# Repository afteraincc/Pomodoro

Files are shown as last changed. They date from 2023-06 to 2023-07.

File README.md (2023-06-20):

>
> 视频介绍：[不会闹铃的番茄时钟](https://www.bilibili.com/video/BV1qc411M7Mi/)
>

### 简介

想法来自“番茄（Pomodoro）工作法”，一种简单易行的时间管理方法。将时间划分为小块，包含专注的工作时间和发散的休息时间。劳逸结合的方式有利于获得较高的工作效率

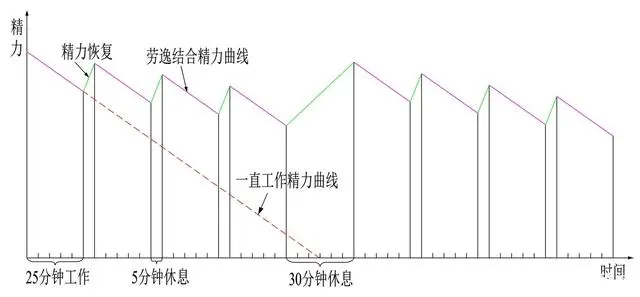
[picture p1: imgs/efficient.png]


### 特色功能

- 简单易用：翻转触发操作

- 劳逸结合：工作状态自动进入休息状态 + 不能关闭的窗口

- 减少干扰：自动开/关即时通讯软件（现支持微信/钉钉）

- 超长续航：长达10小时续航的锂电池，能满足一天的使用

- 插件机制：可以自己实现专用的状态显示效果，例如使用各种开发板附带的例子：点亮LED灯

### 客户端（client目录）

为了能跨平台使用，技术上选择了[Electron](https://www.electronjs.org)

- 编译/构建

	- 先安装[Node.js](https://nodejs.org/en/download)
	
	- 安装依赖

		`npm install`
	
	- 构建

		`npm run build`

- 调试

	由于UI的本质是一个Chrome浏览器，所以可以用Chrome的快捷键`Ctrl + Shift + I`/`Cmd + Opt + I`打开开发者工具
	
- 插件机制

	目录`src/notify-plugins`下新建一个js，模版如下，在感兴趣的状态事件中写相应代码即可
	
	```
	class NotifyPluginXXX {
    onWork() {
    }
    onBreak() {
    }
    onWorkEnd(force) {
    }
    onBreakEnd(force) {
    }
}
export default NotifyPluginXXX
	```

### 固件（fireware目录）

- 显示驱动：TFT_eSPI库

	Visual Studio Code + platformio的配置方法

	```
	配置文件`platformio.ini`增加`build_flags = -I include/tft`，然后`tft_setup.h`放在`include/tft`目录下
	```

- UI：LVGL库

	Visual Studio Code + platformio的配置方法

	```
	配置文件`platformio.ini`增加`build_flags = -I include/lvgl`，然后`lv_conf.h`放在`include/lvgl`目录下
	```

- 陀螺仪MPU6050：I2Cdevlib-MPU6050库

### 硬件（hardware目录）

芯片：USB TypeC接口，ESP32-C3蓝牙，MPU6050陀螺仪，CH340C串口，AMS-1117 3.3V电压转换，IP5306充放电

内容包括原理+PCB和BOM

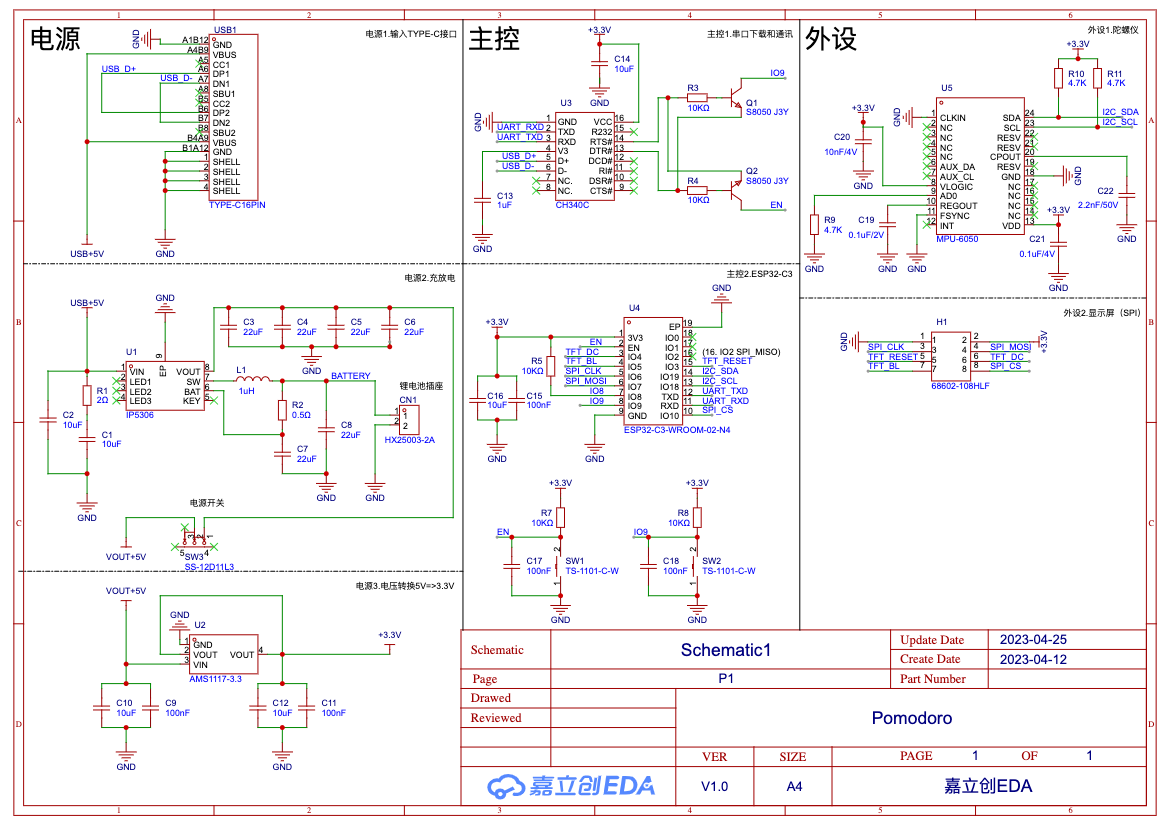
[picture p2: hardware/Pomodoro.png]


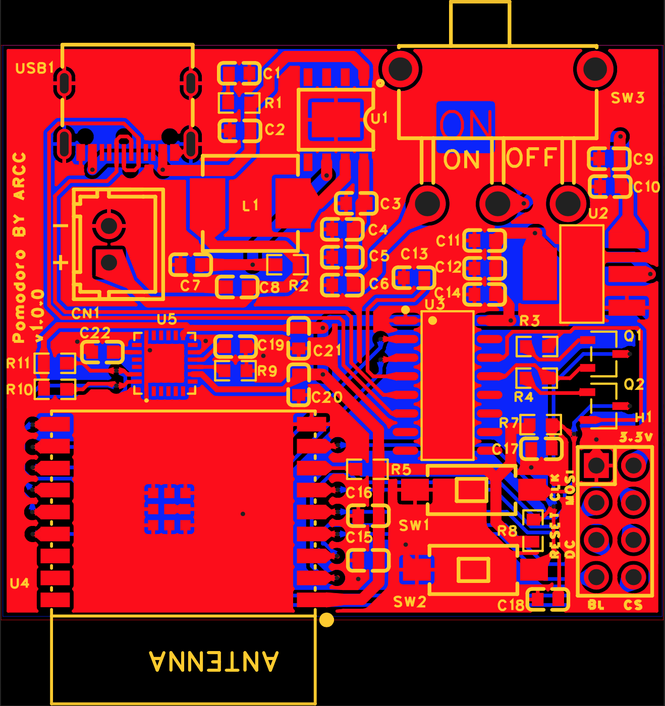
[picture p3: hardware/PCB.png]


### 外壳（3d-model目录）

注意外壳的尺寸是按显示屏和电池定制的，如果选择不同的电池（40x40x10mm）和显示屏（28x40mm）需要注意相应修改

### 注意事项

- ESP32-C3的内存不足

	由于显示屏/蓝牙/陀螺仪用去不少内存，LVGL界面的建议字体最大32，更大的字体容易引起crash（不断循环重启）

- 焊接PCB

	- 焊接IP5306时，底部GND需要焊接到焊盘，否则电压/电流不稳定引起一些奇怪的问题，例如电脑无法识别CH340芯片的串口。建议用风枪+锡膏

	- MPU6050是QFN封装，需要用风枪焊接

- 使用嘉立创EDA（专业版）

	用嘉立创的注意一下，设计时，库里提供的MPU6050是24根引脚，PCB布线时，有一个底部GND无法连接，删除后正常。实际使用下来，发现并不影响功能，主要应该是因为MPU6050本身有一个引脚已经连接到底部GND地线

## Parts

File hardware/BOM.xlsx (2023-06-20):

No. | Quantity | Comment | Designator | Footprint | Value | Manufacturer Part | Manufacturer | Supplier Part | Supplier
1 | 6 | 10uF | C1,C2,C10,C12,C14,C16 | C0603 | 10uF
2 | 6 | 22uF | C3,C4,C5,C6,C7,C8 | C0603 | 22uF
3 | 5 | 100nF | C9,C11,C15,C17,C18 | C0603 | 100nF
4 | 1 | 1uF | C13 | C0603 | 1uF
5 | 1 | 0.1uF/2V | C19 | C0603 | 0.1uF/2V
6 | 1 | 10nF/4V | C20 | C0603 | 10nF/4V
7 | 1 | 0.1uF/4V | C21 | C0603 | 0.1uF/4V
8 | 1 | 2.2nF/50V | C22 | C0603 | 2.2nF/50V
9 | 1 | HX25003-2A | CN1 | CONN-TH_2P-P2.50_HX25003-2A |  | HX25003-2A | HX(红星) | C442299 | LCSC
10 | 1 | 68602-108HLF | H1 | HDR-TH_8P-P2.54-V-M-R2-C4-S2.54 |  | 68602-108HLF | Amphenol | C168672 | LCSC
11 | 1 | 1uH | L1 | IND-SMD_L6.5-W6.5_IHLP-2525 | 1uH | IHLP2525CZER1R0M01 | VISHAY(威世) | C845018 | LCSC
12 | 2 | S8050 J3Y | Q1,Q2 | SOT-23-3_L3.0-W1.7-P0.95-LS2.9-BR |  | S8050 J3Y | CJ（江苏长电/长晶） | C2146 | LCSC
13 | 1 | 2Ω | R1 | R0603 | 2Ω
14 | 1 | 0.5Ω | R2 | R0603 | 0.5Ω
15 | 5 | 10KΩ | R3,R4,R5,R7,R8 | R0603 | 10KΩ
16 | 3 | 4.7K | R9,R10,R11 | R0603 | 4.7K
17 | 2 | TS-1101-C-W | SW1,SW2 | SW-SMD_L6.0-W3.3-LS8.0 |  | TS-1101-C-W | XKB Connectivity(中国星坤) | C318938 | LCSC
18 | 1 | SS-12D11L3 | SW3 | SW-TH_SS-12D11L3 |  | SS-12D11L3 | XKB Connectivity(中国星坤) | C843366 | LCSC
19 | 1 | IP5306 | U1 | ESOP-8_L4.9-W3.9-P1.27-LS6.0-BL-EP |  | IP5306 | INJOINIC(英集芯) | C181692 | LCSC
20 | 1 | AMS1117-3.3 | U2 | SOT-223-3_L6.5-W3.4-P2.30-LS7.0-BR |  | AMS1117-3.3 | AMS | C6186 | LCSC
21 | 1 | CH340C | U3 | SOP-16_L10.0-W3.9-P1.27-LS6.0-BL |  | CH340C | WCH(南京沁恒) | C84681 | LCSC
22 | 1 | ESP32-C3-WROOM-02-N4 | U4 | BULETM-SMD_ESPRESSIF_ESP32-C3-WROOM-02-N4-4MB |  | ESP32-C3-WROOM-02-N4 | ESPRESSIF(乐鑫) | C2934560 | LCSC
23 | 1 | MPU-6050 | U5 | QFN-24_L4.0-W4.0-P0.50-BL-MPU-6050 |  | MPU-6050 | TDK InvenSense(应美盛) | C24112 | LCSC
24 | 1 | TYPE-C16PIN | USB1 | USB-C-SMD_TYPE-C16PIN |  | TYPE-C16PIN | SHOU HAN(首韩) | C393939 | LCSC

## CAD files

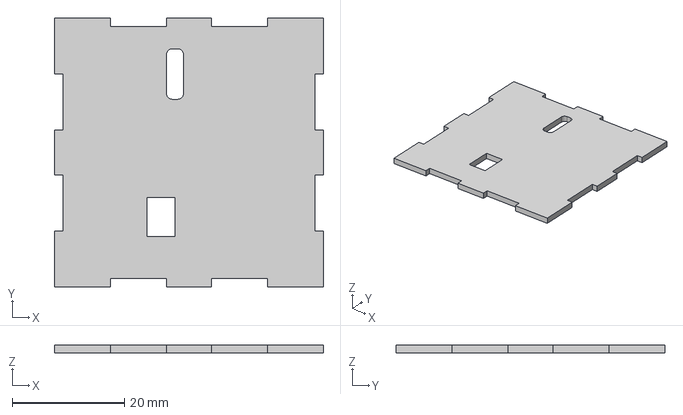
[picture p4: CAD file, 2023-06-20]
3d-model/lid.step
48.0 x 48.0 x 1.50 mm

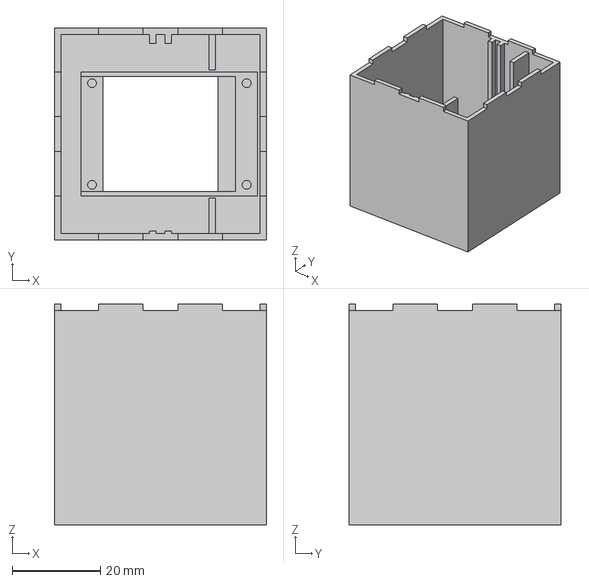
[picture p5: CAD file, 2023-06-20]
3d-model/box.step
48.0 x 48.0 x 50.0 mm

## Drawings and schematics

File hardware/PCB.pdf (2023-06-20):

# ONONOFF

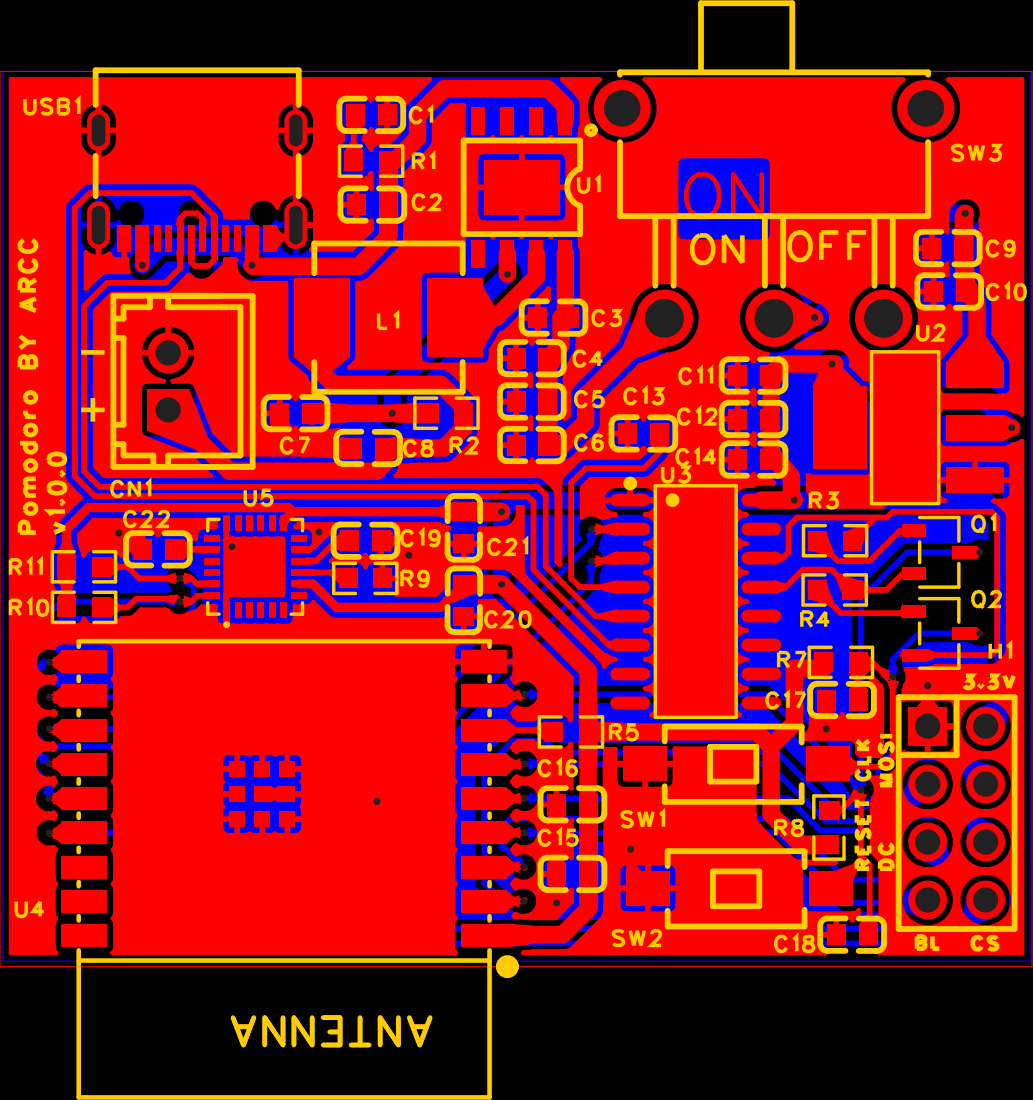
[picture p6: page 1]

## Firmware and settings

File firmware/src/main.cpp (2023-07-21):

#include <Arduino.h>
#include <Esp.h>
#include <Ticker.h>
#include "ble.h"
#include "cfg.h"
#include "screen.h"
#include "mainpage.h"
#include "loopticker.h"
#include "cube.h"

static Screen screen;
static MainPage mainPage;

static PomodoroBLE *pomodoroBLE = NULL;
static PomodoroStatus pomodoroStatus = PomodoroStatus::Idle;
static bool isAutoBreak = false;

static Ticker timer;
static uint32_t secondNum = 0;
static uint32_t timeoutRetryCount = 3; // 超时通知重试次数(秒数)，确保客户端接收到结束消息

// longIntervalSecond: 未连接时，BLE定时广播
static LoopTicker loopTicker(5, 10, 1);

static Cube cube;
static int preFaceId = 0;

void echoSystemInfo()
{
  Serial.printf("chip revision: %d\n", ESP.getChipRevision());
  Serial.printf("chip model: %s\n", ESP.getChipModel());
  Serial.printf("chip cores: %d\n", ESP.getChipCores());
  Serial.printf("cpu FreqMHz: %d\n", ESP.getCpuFreqMHz());
  Serial.printf("sdk version: %s\n", ESP.getSdkVersion());

  Serial.printf("heap size: %d\n", ESP.getHeapSize());
  Serial.printf("free heap: %d\n", ESP.getFreeHeap());
  Serial.printf("mini free heap: %d\n", ESP.getMinFreeHeap());
  Serial.printf("max alloc heap: %d\n", ESP.getMaxAllocHeap());

  Serial.printf("psram size: %d\n", ESP.getPsramSize());
  Serial.printf("free psram: %d\n", ESP.getFreePsram());
  Serial.printf("mini free psram: %d\n", ESP.getMinFreePsram());
  Serial.printf("max alloc psram: %d\n", ESP.getMaxAllocPsram());

  Serial.printf("flash size: %d\n", ESP.getFlashChipSize());
  Serial.printf("flash speed: %d\n", ESP.getFlashChipSpeed());
  Serial.printf("flash mode: %d\n", ESP.getFlashChipMode());
}

void initScreen()
{
  screen.init(240, 240);
  mainPage.init();
  lv_timer_handler();
}

void initBLE()
{
  PomodoroCfg.loadCfg();

  pomodoroBLE = new PomodoroBLE();
  pomodoroBLE->setWorkMinute(PomodoroCfg.getWorkMinute());
  pomodoroBLE->init();
  Serial.printf("PomodoroBLE work minute: %d\n", pomodoroBLE->getWorkMinute());

  mainPage.updateWorkProgress(pomodoroBLE->getWorkMinute() * 60, 0);
}

void setup()
{
  Serial.begin(115200);
  echoSystemInfo();

  initScreen();
  initBLE();

  cube.init();
}

bool workTriggerOn()
{
  return !digitalRead(0x9);
}

bool cancelTimer()
{
  if (!timer.active())
    return false;

  timer.detach();
  return true;
}

void breakTriggerHandle();
void IRAM_ATTR onWorkTimer()
{
  bool timeout = false;
  bool timeoutRetrying = false;

  secondNum++;
  if (secondNum > pomodoroBLE->getWorkMinute() * 60)
    timeoutRetrying = true;
  if (secondNum > pomodoroBLE->getWorkMinute() * 60 + timeoutRetryCount)
    timeout = true;

  if (timeout)
  {
    isAutoBreak = true;
    breakTriggerHandle();
  }
  else
  {
    Serial.printf("PomodoroBLE::notify clientConnected: %d, status %d, total %d, second %d\n",
                  pomodoroBLE->clientConnected(), PomodoroStatus::Working, pomodoroBLE->getWorkMinute() * 60, secondNum);
    pomodoroBLE->notify(PomodoroStatus::Working, pomodoroBLE->getWorkMinute() * 60, secondNum);
    if (!timeoutRetrying)
      mainPage.updateWorkProgress(pomodoroBLE->getWorkMinute() * 60, secondNum);
    else
    {
      mainPage.updateWorkProgress(pomodoroBLE->getWorkMinute() * 60, 0);
      mainPage.workOff();
    }
  }
}

void IRAM_ATTR onBreakTimer()
{
  bool timeout = false;
  bool timeoutRetrying = false;

  secondNum++;
  if (secondNum > pomodoroBLE->getBreakMinute() * 60)
    timeoutRetrying = true;
  if (secondNum > pomodoroBLE->getBreakMinute() * 60 + timeoutRetryCount)
    timeout = true;

  if (timeout)
    cancelTimer();
  else
  {
    Serial.printf("PomodoroBLE::notify clientConnected: %d, status %d, total %d, second %d\n",
                  pomodoroBLE->clientConnected(), PomodoroStatus::Break, pomodoroBLE->getBreakMinute() * 60, secondNum);
    pomodoroBLE->notify(PomodoroStatus::Break, pomodoroBLE->getBreakMinute() * 60, secondNum);
    if (!timeoutRetrying)
      mainPage.updateBreakProgress(pomodoroBLE->getBreakMinute() * 60, secondNum);
    else
    {
      mainPage.updateWorkProgress(pomodoroBLE->getBreakMinute() * 60, 0);
      mainPage.breakOff();
    }
  }
}

void IRAM_ATTR onIdleTimer()
{
  bool timeout = false;
  int idleSeconds = 3;

  secondNum++;
  if (secondNum > idleSeconds)
    timeout = true;

  if (timeout)
  {
    mainPage.updateWorkProgress(pomodoroBLE->getWorkMinute() * 60, 0);
    cancelTimer();
  }
  else
  {
    Serial.printf("PomodoroBLE::notify clientConnected: %d, status %d, total %d, second %d\n",
                  pomodoroBLE->clientConnected(), PomodoroStatus::Idle, idleSeconds, secondNum);
    pomodoroBLE->notify(PomodoroStatus::Idle, idleSeconds, secondNum);
    mainPage.updateBreakProgress(idleSeconds, secondNum);
  }
}

bool startWorkTimer()
{
  if (PomodoroStatus::Working == pomodoroStatus)
    return false;
  if (isAutoBreak)
    return false;

  if (timer.active())
    cancelTimer();

  secondNum = 0;

  timer.attach(1, onWorkTimer);
  pomodoroStatus = PomodoroStatus::Working;
  return true;
}

bool startBreakTimer()
{
  if (PomodoroStatus::Break == pomodoroStatus)
    return false;

  if (timer.active())
    cancelTimer();

  secondNum = 0;

  timer.attach(1, onBreakTimer);
  pomodoroStatus = PomodoroStatus::Break;
  return true;
}

bool startIdleTimer()
{
  if (PomodoroStatus::Idle == pomodoroStatus)
    return false;

  if (timer.active())
    cancelTimer();

  secondNum = 0;

  timer.attach(1, onIdleTimer);
  pomodoroStatus = PomodoroStatus::Idle;
  return true;
}

void pomodoroBLEAdvertising()
{
  if (pomodoroBLE->clientConnected())
    return;

  Serial.printf("BLE advertising\n");
  pomodoroBLE->advertising();
}

void updateWorkMinute()
{
  if (!pomodoroBLE->workMinuteIsUpdated())
    return;

  PomodoroCfg.setWorkMinute(pomodoroBLE->getWorkMinute());
  PomodoroCfg.saveCfg();
  pomodoroBLE->updateWorkMinute();

  mainPage.updateWorkProgress(pomodoroBLE->getWorkMinute() * 60, 0);
}

void updateConnectStatus()
{
  if (pomodoroBLE->clientConnected())
    mainPage.connectOn();
  else
  {
    mainPage.updateWorkProgress(pomodoroBLE->getWorkMinute() * 60, 0);
    mainPage.workOff();
    mainPage.breakOff();
    mainPage.connectOff();

    cancelTimer();
  }
}

void workTriggerHandle()
{
  if (startWorkTimer())
  {
    Serial.printf("isWorkFace\n");
    mainPage.breakOff();
    mainPage.workOn();
    mainPage.updateWorkProgress(pomodoroBLE->getWorkMinute() * 60, 0);
    screen.rotate(LV_DISP_ROT_270);
  }
}

void breakTriggerHandle()
{
  if (startBreakTimer())
  {
    Serial.printf("isBreakFace\n");
    mainPage.workOff();
    mainPage.breakOn();
    mainPage.updateBreakProgress(pomodoroBLE->getBreakMinute() * 60, 0);
    if (!isAutoBreak)
      screen.rotate(LV_DISP_ROT_90);
  }
}

void idleTriggerHandle()
{
  if (startIdleTimer())
  {
    Serial.printf("isIdleFace\n");
    mainPage.breakOff();
    mainPage.workOff();
    mainPage.updateWorkProgress(pomodoroBLE->getWorkMinute() * 60, 0);
    screen.rotate(LV_DISP_ROT_NONE);
  }
}

void triggerHandle()
{
  if (!cube.readYawPitchRoll())
    return;
  mainPage.updateYawPitchRoll(cube.getYaw(), cube.getPitch(), cube.getRoll());

  if (!pomodoroBLE->clientConnected())
    return;

  // fixbug: sometimes get corrupt data => try twice
  if (cube.currentFaceId() != preFaceId)
  {
    preFaceId = cube.currentFaceId();
    return;
  }

  if (cube.isWorkFace() || workTriggerOn())
    workTriggerHandle();
  else if (cube.isBreakFace())
  {
    isAutoBreak = false;
    breakTriggerHandle();
  }
  else if (cube.isIdleFace())
  {
    isAutoBreak = false;
    idleTriggerHandle();
  }
}

void loop()
{
  lv_timer_handler();
  delay(loopTicker.getTickMilliSecond());

  loopTicker.tick();
  if (loopTicker.longIntervalArrived())
  {
    loopTicker.resetLongInterval();

    pomodoroBLEAdvertising();
  }

  if (loopTicker.shortIntervalArrived())
  {
    loopTicker.resetShortInterval();

    updateWorkMinute();
    updateConnectStatus();
    triggerHandle();
  }
}

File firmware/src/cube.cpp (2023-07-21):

#include "cube.h"
#include "I2Cdev.h"
#include "MPU6050_6Axis_MotionApps20.h"
#include <Wire.h>

static MPU6050 mpu;
static uint8_t fifoBuffer[64]; // FIFO storage buffer
                               // orientation/motion vars
static Quaternion q;           // [w, x, y, z]         quaternion container
static VectorFloat gravity;    // [x, y, z]            gravity vector
static float euler[3];         // [psi, theta, phi]    Euler angle container
static float temp[3];          // [yaw, pitch, roll]   yaw/pitch/roll container and gravity vector

void Cube::init()
{
    delta = 10;

    Wire.begin(19, 18);
    Wire.setClock(400000); // 400kHz I2C clock. Comment this line if having compilation difficulties
    mpu.initialize();
    devStatus = mpu.dmpInitialize();

    //// supply your own gyro offsets here, scaled for min sensitivity
    // mpu.setXGyroOffset(-1);
    // mpu.setYGyroOffset(-10);
    // mpu.setZGyroOffset(64);
    // mpu.setZAccelOffset(816);

    if (0 == devStatus)
    {
        // Calibration Time: generate offsets and calibrate our MPU6050
        mpu.CalibrateAccel(6);
        mpu.CalibrateGyro(6);
        mpu.PrintActiveOffsets();
        // turn on the DMP, now that it's ready
        mpu.setDMPEnabled(true);
    }
}
bool Cube::isSuccessed()
{
    return (0 == devStatus);
}

bool Cube::readYawPitchRoll()
{
    if (0 != devStatus)
        return false;

    // read a packet from FIFO
    // Get the Latest packet
    if (0 == mpu.dmpGetCurrentFIFOPacket(fifoBuffer))
        return false;

    // return Euler angles in degrees
    mpu.dmpGetQuaternion(&q, fifoBuffer);
    mpu.dmpGetGravity(&gravity, &q);
    mpu.dmpGetYawPitchRoll(temp, &q, &gravity);
    ypr[0] = temp[0] * 180 / M_PI;
    ypr[1] = temp[1] * 180 / M_PI;
    ypr[2] = temp[2] * 180 / M_PI;

    return true;
}

int Cube::getYaw()
{
    return ypr[0];
}

int Cube::getPitch()
{
    return ypr[1];
}

int Cube::getRoll()
{
    return ypr[2];
}

bool Cube::isWorkFace()
{
    int t = 0;

    t = getRoll();
    if (t > 90 + delta || t < 90 - delta)
        return false;

    return true;
}

bool Cube::isIdleFace()
{
    int t = 0;

    t = getRoll();
    if (t > 0 + delta || t < 0 - delta)
        return false;

    return true;
}

bool Cube::isBreakFace()
{
    int t = 0;

    t = getRoll();
    if (t > -90 + delta || t < -90 - delta)
        return false;

    return true;
}

int Cube::currentFaceId()
{
    if (isWorkFace())
        return 2;
    else if (isIdleFace())
        return 3;
    else if (isBreakFace())
        return 5;

    return 0;
}

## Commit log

2023-06-20 initial code
    [BOM.xlsx, box.step, lid.step]
2023-06-20 add hardware/PCB.pdf
2023-06-20 add hardware/PCB.png(github can't display pdf)
2023-07-21 fixbug: sometimes get corrupt data => try twice
    [cube.cpp, main.cpp]
